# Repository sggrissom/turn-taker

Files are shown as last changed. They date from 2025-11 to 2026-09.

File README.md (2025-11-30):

# Turn Taker - RP2040 + SSD1315 OLED Project

A Raspberry Pi Pico project with SSD1315/SSD1306 I2C OLED display support.

## Prerequisites

1. **Pico SDK** - Install the Raspberry Pi Pico SDK:
   ```bash
   git clone https://github.com/raspberrypi/pico-sdk.git
   cd pico-sdk
   git submodule update --init
   export PICO_SDK_PATH=$(pwd)
   ```

2. **ARM Toolchain**:
   ```bash
   # Arch Linux
   sudo pacman -S arm-none-eabi-gcc arm-none-eabi-newlib

   # Ubuntu/Debian
   sudo apt install gcc-arm-none-eabi libnewlib-arm-none-eabi
   ```

3. **CMake** (version 3.13+):
   ```bash
   # Arch Linux
   sudo pacman -S cmake

   # Ubuntu/Debian
   sudo apt install cmake
   ```

## Wiring

Connect the SSD1315 OLED display to the Pico:

| Pico Pin | GPIO | Display Pin | Description  |
|---|---|---|---|
| 6 | GP4  | SDA | I2C Data |
| 7 | GP5  | SCL | I2C Clock |
| 36 | 3V3  | VCC | Power (3.3V) |
| 38 | GND  | GND | Ground |

```
         ┌─────────────────┐
         │  Raspberry Pi   │
         │      Pico       │
         │                 │
    SDA ─┤ GP4 (pin 6)     │
    SCL ─┤ GP5 (pin 7)     │
    VCC ─┤ 3V3 (pin 36)    │
    GND ─┤ GND (pin 38)    │
         └─────────────────┘
```

## Building

1. Set the SDK path (if not already set):
   ```bash
   export PICO_SDK_PATH=/path/to/pico-sdk
   ```

2. Create build directory and compile:
   ```bash
   mkdir build && cd build
   cmake ..
   make
   ```

3. The build produces `turn_taker.uf2` in the build directory.

## Flashing

1. Hold the **BOOTSEL** button on the Pico while connecting USB
2. The Pico will appear as a USB mass storage device (RPI-RP2)
3. Copy `turn_taker.uf2` to the device:
   ```bash
   cp build/turn_taker.uf2 /run/media/$USER/RPI-RP2/
   ```
4. The Pico will automatically reboot and run the program

## Configuration

Edit `include/config.h` to change:
- I2C pins (default: GP4/GP5)
- Display dimensions (default: 128x64)
- I2C address (default: 0x3C)

## Display Driver API

```c
// Initialize display
ssd1306_init(&display, I2C_PORT, addr, width, height);

// Clear buffer
ssd1306_clear(&display);

// Drawing functions
ssd1306_draw_pixel(&display, x, y, color);
ssd1306_draw_line(&display, x0, y0, x1, y1, color);
ssd1306_draw_rect(&display, x, y, w, h, color);
ssd1306_fill_rect(&display, x, y, w, h, color);
ssd1306_draw_char(&display, x, y, 'A', color);
ssd1306_draw_string(&display, x, y, "Hello", color);

// Send buffer to display
ssd1306_display(&display);

// Other controls
ssd1306_set_contrast(&display, 0xFF);
ssd1306_invert(&display, true);
```

## USB Serial Debug

The project is configured to output to USB serial. Connect via:
```bash
# Find the device
ls /dev/ttyACM*

# Connect (e.g., using minicom)
minicom -D /dev/ttyACM0 -b 115200
```

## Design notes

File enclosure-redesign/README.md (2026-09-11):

# Turn Taker — parametric enclosure (revision 1)

A code-driven replacement for the simple open-topped cup in
`../turn-taker/turn-taker/turn-taker/turn-taker.FCStd`. Nothing in the original
KiCad / FreeCAD / STEP files was modified — they are only read.

```
enclosure-redesign/
    enclosure.py        the whole model, parameters at the top
    README.md
    output/
        base.step  base.stl
        lid.step   lid.stl
        lid_print.stl           lid flipped + dropped to z=0, ready to slice
        button_plunger.step/.stl  optional, print 2 off
        build-report.txt        full validation log from the last run
        preview_*.png
```

## Building

```bash
cd enclosure-redesign
freecadcmd enclosure.py          # ~70 s, regenerates everything in output/
```

Requires FreeCAD ≥ 1.0 (1.1.1 here) with `numpy` + `matplotlib` for the
previews. No GUI, no CadQuery, no virtualenv — CadQuery was not installed and
FreeCAD headless already reads the KiCad STEP directly, so there was no reason
to add a dependency. Editing the model means editing the parameter block at the
top of `enclosure.py` and re-running; the script re-validates and re-exports
every time.

## Coordinate system

| | |
|---|---|
| X, Y | centred on the round PCB axis, Y up when looking at the component side |
| Z | 0 at the outside bottom of the base, +Z toward the lid |

Mapping from the KiCad STEP export:

```
x_local = x_step - 181.533565
y_local = y_step +  86.500000      (the STEP already has y = -kicad_y)
z_local = z_step + PCB_BOTTOM_Z    (the STEP has the PCB underside at z = 0)
```

## What the CAD told us

Everything below marked **derived** came out of `turn-taker.kicad_pcb`,
`turn-taker-PTH.drl` or `turn-taker.step`. Nothing here was guessed.

| Item | Value | Source |
|---|---|---|
| **PCB diameter** | **65.067 mm** (R 32.533565) | `Edge.Cuts` circle, centre (181.533565, 86.5) |
| PCB thickness | 1.51 mm in the STEP, **1.60 mm used** | STEP solid / KiCad nominal |
| Longest pin protrusion below the board | **1.91 mm** (SW1/SW2 legs) | STEP `ZMin = -1.905` |
| Plated through-holes | 62 | `turn-taker-PTH.drl` |
| Mounting holes usable for the case | **none** | the only NPTH are 4 holes inside the Pico footprint |
| Bottom-side components | **none** | `B_Paste.gbr` is empty — everything is THT |
| SW1 actuator | R 1.75 mm at (−19.884, +0.250), top 4.385 mm above the board | R1.75 cylinder in the STEP |
| SW2 actuator | R 1.75 mm at (−19.884, −14.250), same height | ditto |
| Tallest component | **J2, 8.54 mm** above the PCB top face | STEP bounding boxes |
| Pico USB micro-B | 7.50 mm wide at local X −0.259, 1.085–3.535 mm above the board, face 2.2 mm inside the board edge | STEP section at the Pico's USB end |
| S1 (power slide switch) | pads at local (18.466, +5.0 / +0.3 / −4.4); courtyard 7.3 × 13.2 mm | `kicad_pcb` pads + `F.CrtYd` |
| Bat_In1 | horizontal JST-PH, entirely inside R 29.7 | STEP |

Net check from the schematic: **SW1 → GPIO14** (back / undo),
**SW2 → GPIO15** (next person), **J1 → the OLED** (GND, +5V, GP4/SDA, GP5/SCL),
**J2 + S1 → battery switching**, **Bat_In1 → battery**.

Component heights above the PCB top face:

| | mm |
|---|---|
| J2 (power header) | 8.54 |
| J1 (display connector) | 6.00 |
| Bat_In1 | 4.85 |
| SW1 / SW2 | 4.30 |
| A1 Pico (incl. USB) | 3.70 |

## The enclosure

Overall **Ø70.067 × 26.80 mm**. Base 24.60 mm tall, lid 2.20 mm on top of it.

### Key dimensions

| Parameter | Value |
|---|---|
| PCB radial clearance (`PCB_RADIAL_CLEAR`) | 0.50 mm → cavity R 33.034 |
| Wall thickness (`WALL_T`) | 2.00 mm → outer R 35.034 |
| Floor thickness (`FLOOR_T`) | 2.00 mm |
| Lid thickness (`LID_T`) | 2.20 mm |
| PCB elevation above the floor (`PCB_ELEVATION`) | 5.00 mm → PCB underside at z = 7.00, top face at z = 8.60 |
| PCB support height | 5.00 mm (3.09 mm spare over the 1.91 mm pin protrusion) |
| Lid internal clearance (`LID_INTERIOR_CLEAR`) | 16.00 mm above the PCB top face → lid underside at z = 24.60, **7.46 mm of headroom over J2** |
| Lid fit clearance (`LID_FIT_CLEAR`) | 0.30 mm radial / 0.60 mm diametral |
| Lid skirt | Ø65.47 outer, 2.00 mm thick, 4.00 mm deep, 0.80 mm lead-in chamfer |

### PCB support

Two things hold the board, and neither touches a solder joint:

1. **A continuous annular ledge** at z = 7.00, inner radius 31.43 mm
   (`LEDGE_W = 1.6`), giving **1.10 mm of bearing** all the way round. The
   outermost through-hole in the whole board is at R 29.11, so the ledge is
   clear of every pin by construction. Because the cavity *widens* going up,
   the ledge is a step, not an overhang — it needs no print support.
2. **Nine Ø5 mm posts** from the floor to z = 7.00, listed in `SUPPORT_POSTS`.
   The script checks every post against all 62 plated holes; the worst case is
   **4.73 mm** centre-to-centre, against a 4.10 mm requirement (post radius +
   a 1.6 mm assumed solder-joint radius). One post sits deliberately at
   (−19.9, −7.0), between SW1 and SW2, so button presses don't flex the board.

The board drops in from above, sits level, and cannot rock. There is no
retention clip yet — that was explicitly deferred.

### Lid openings

| Opening | Size | Centre (local X, Y) |
|---|---|---|
| **SW1 button** | Ø6.00 mm | (−19.884, +0.250) |
| **SW2 button** | Ø6.00 mm | (−19.884, −14.250) |
| **Display window** | 24.0 × 15.0 mm, R1.2 corners | (−0.70, **−7.00**) |
| Display module recess (in the lid underside) | 28.3 × 28.8 × 1.40 mm deep | (−0.70, −3.40) |
| **S1 power switch slot** | 7.0 × 13.0 mm, R1.5 corners | (18.466, +0.300) |
| **USB micro-B** (in the base wall) | 13.0 × 8.0 mm | X −6.76…+6.24, Z 7.20…15.20 |
| Lid pry notch (base rim) | R6.0 × 1.6 mm deep scallop | at 270°, i.e. (0, −35.03) |

Button openings are 6.00 mm over a 3.50 mm actuator — **1.25 mm of annular
clearance**, so print tolerance and lid misalignment can't jam them.

The USB slot is sized for a plug overmould, not just the receptacle: the port
face sits 2.2 mm inside the board edge and there is another 2.0 mm of wall, so
the plug has to enter the case by about 5 mm before it engages.

### Edge access

- **Pico USB micro-B** — reaches the perimeter, so it gets a side slot. This is
  both the charging/serial port and the BOOTSEL flashing path, so it is not
  optional.
- **S1 power switch** — sits ~10 mm inside the board edge, so a side opening is
  geometrically impossible. It gets a slot in the lid instead (see assumptions).
- **Bat_In1 / J1 / J2** — entirely internal (max radius 29.7 mm); no openings,
  per the brief.

## Printing

0.4 mm nozzle, ordinary PLA/PETG settings. **Neither part needs supports.**

| Part | Orientation | Notes |
|---|---|---|
| `base.stl` | as exported, floor on the bed | Longest bridge is the 13 mm USB slot roof. The PCB ledge is a step that narrows going up, so it self-supports. |
| `lid_print.stl` | as exported (already flipped, outer face on the bed) | Gives the best finish on the visible face. `lid.stl` is the same part in assembly position if you'd rather orient it yourself. |
| `button_plunger.stl` | as exported, stem down — **print 2** | The flange overhang is picked up by a 45° cone. |

Minimum wall anywhere is 2.00 mm, except the 0.80 mm bezel that remains over
the display recess (4 layers at 0.2 mm).

## Assembly

1. Drop the two plungers into the lid's button holes **from underneath** (the
   8.5 mm flange won't pass through the 6 mm hole).
2. Seat the OLED module face-down into the lid recess and tape/glue it; route
   its 4 wires to J1.
3. Lower the PCB into the base — it lands on the ledge and the nine posts.
   Check the USB port lines up with the wall slot.
4. Press the lid on. The skirt locates it; 0.30 mm radial clearance should give
   a light friction fit. To open, push up through the pry notch in the rim.

## Assumptions (things the CAD could not tell us)

These are the only guesses in the model. Each is a parameter near the top of
`enclosure.py`.

1. **Display position and size.** There is *no display footprint on the PCB* —
   the SSD1315 is a separate module on flying leads to J1, so nothing in the
   CAD says where it physically sits. Dimensions assume the ubiquitous 0.96"
   4-pin I²C OLED: **27.3 × 27.8 mm module PCB, 21.74 × 10.86 mm active area**.
   The module is mounted **to the lid** (recess + window), which also keeps it
   clear of everything on the board. Position was chosen so the window centres
   on the midpoint between SW1 and SW2. Adjust `DISPLAY_MODULE_W/H`,
   `DISPLAY_CENTER`, `DISPLAY_WINDOW_W/H` and `DISPLAY_WINDOW_OFFSET`.
   *Measure your actual module before printing the lid.*
2. **S1 actuator.** Its footprint position is derived, but there is no 3D model
   for it, so its body and actuator height are unknown. The 7 × 13 mm lid slot
   covers the courtyard with clearance. With the lid 16 mm above the board this
   is a fingernail/stylus reach, not a comfortable thumb slide — a printed
   slider is a good rev-2 addition.
3. **Button reach.** The brief asked for plain holes so buttons could be pressed
   directly, but J2's 8.5 mm header sets the internal height, which leaves the
   actuators **13.82 mm below the lid's outer face** — far too deep for a
   fingertip through a 6 mm hole. The holes are still plain (a pen works), and
   the optional `button_plunger` bridges the gap properly. Set
   `BUTTON_PLUNGER_ENABLE = False` if you don't want them.
4. **Wiring volume.** `LID_INTERIOR_CLEAR = 16.00` is deliberately generous —
   8.54 mm of it is J2, the remaining 7.46 mm is for the display's flying
   leads and for a Dupont shell on J2 if you use one. Reduce it to ~12 mm if
   you solder wires directly and want a slimmer puck.
5. **Battery.** Bat_In1 implies a LiPo, but nothing in the CAD says where it
   lives. The model assumes it goes in the volume above the board. If you want
   it *under* the board instead, raise `PCB_ELEVATION` — there is currently
   only 5.00 mm there, 1.91 mm of which is pin protrusion.
6. **Solder joint size.** Posts are kept 1.6 mm (`POST_KEEPOUT`) away from any
   hole centre, on top of the post radius.
7. **PCB thickness.** The STEP solid is 1.51 mm; 1.60 mm is used so the pocket
   is never tight.

## Validation

`enclosure.py` runs 35 checks on every build and writes them to
`output/build-report.txt`. They cover: PCB fit and ledge bearing, pin
clearance, every support post against all 62 drilled holes, boolean
intersection of both enclosure parts against the real PCB assembly imported
from the STEP, lid headroom vs. the tallest component, button holes vs. the
actual actuator axes, plunger fit and travel, display window/recess layout and
its margins to the other lid features, skirt clearance, USB slot alignment
against the real port bounding box, minimum wall thickness, bridge length, and
a watertight/manifold/self-intersection check on each exported mesh.

Last run: **35/35 passed**, all three meshes watertight, manifold and free of
self-intersections.

## Previews

| File | |
|---|---|
| `preview_base.png` | base alone |
| `preview_lid_top.png` / `preview_lid_bottom.png` | lid outside / inside |
| `preview_top.png` | lid layout looking straight down |
| `preview_pcb_in_base.png` | PCB seated in the base |
| `preview_exploded.png` | exploded assembly |
| `preview_assembled.png` | assembled |
| `preview_section.png` | vertical section — ledge, posts, plunger, stack-up |

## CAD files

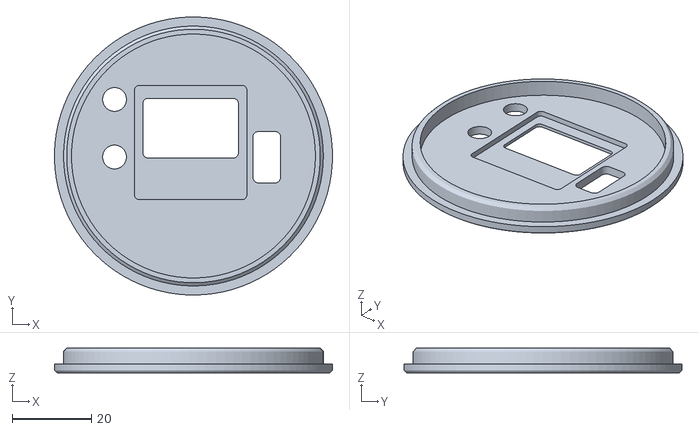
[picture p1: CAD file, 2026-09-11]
enclosure-redesign/output/lid_print.stl
70.0 x 70.1 x 6.20

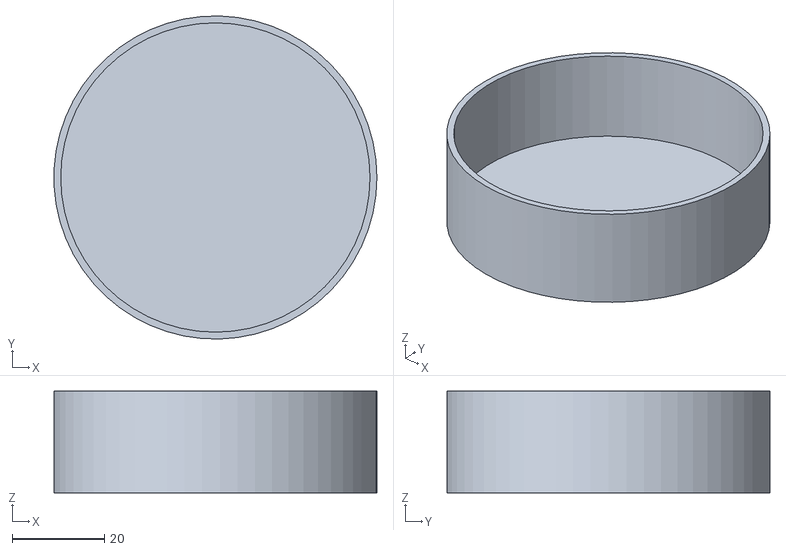
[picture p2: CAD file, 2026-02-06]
turn-taker/turn-taker/turn-taker/turn-taker-base.stl
69.9 x 70.0 x 22.0

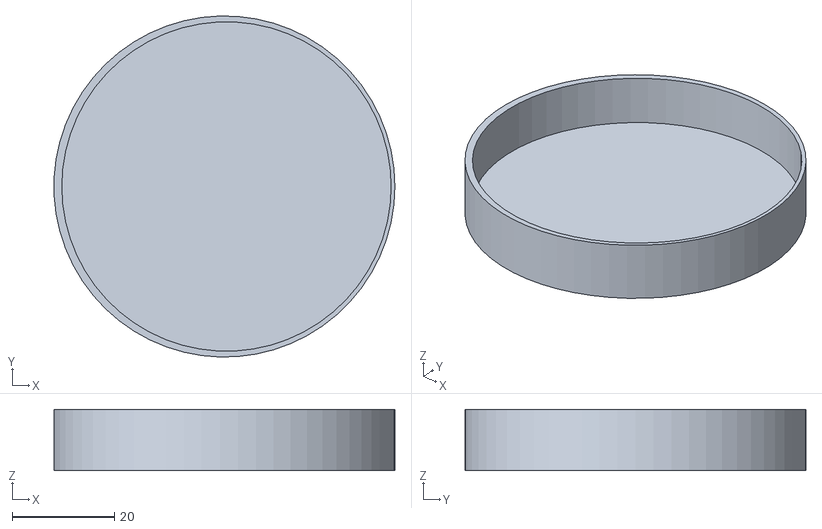
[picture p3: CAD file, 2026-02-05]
turn-taker/turn-taker/turn-taker/turn-taker-BodyPocket.stl
66.7 x 66.8 x 12.0

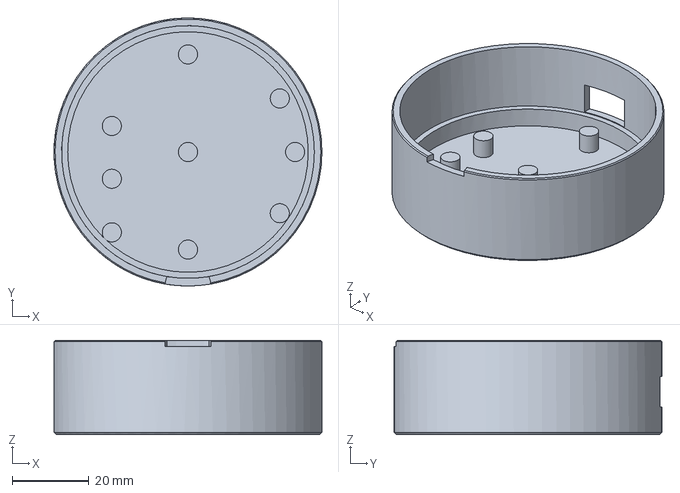
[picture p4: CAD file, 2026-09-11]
enclosure-redesign/output/base.step
70.1 x 70.1 x 24.6 mm

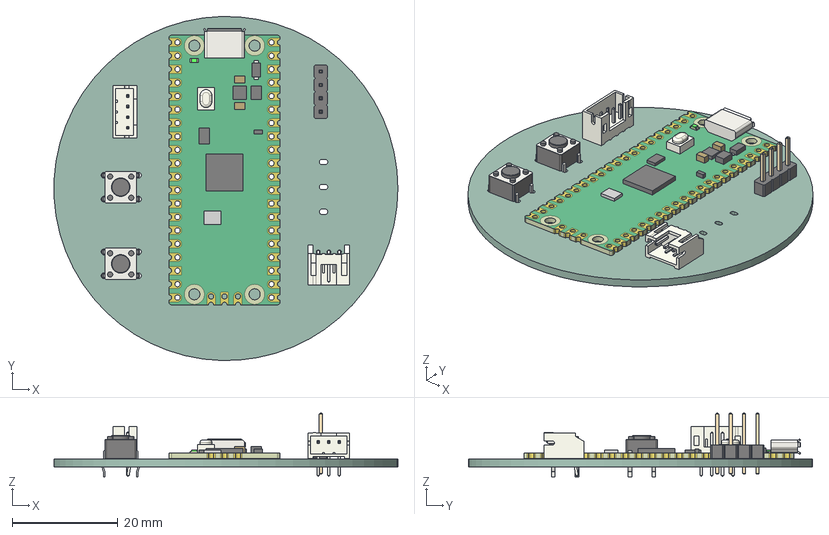
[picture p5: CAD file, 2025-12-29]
turn-taker/turn-taker/turn-taker/turn-taker.step
65.0 x 65.0 x 12.0 mm
RaspberryPi_Pico_Module_KiCad
PinHeader_1x04_P2.54mm_Vertical
SW_PUSH_6mm x 2
JST_PH_B4B-PH-K_1x04_P2.00mm_Vertical
JST_PH_S3B-PH-K_1x03_P2.00mm_Horizontal
turn-taker_PCB

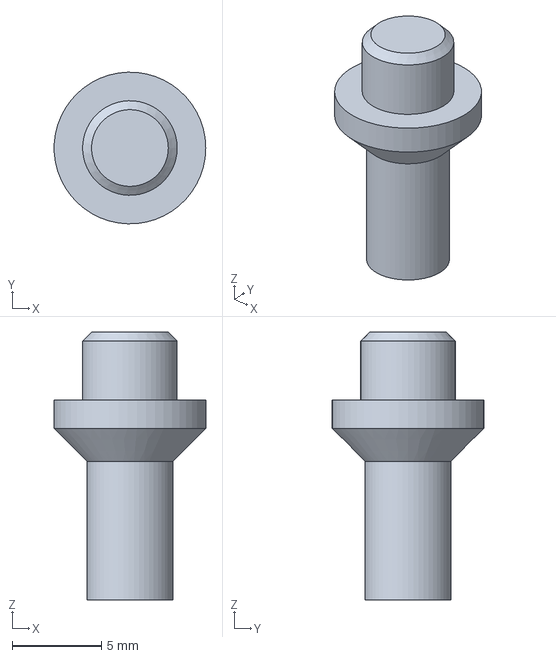
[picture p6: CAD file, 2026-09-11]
enclosure-redesign/output/button_plunger.step
8.49 x 8.50 x 15.0 mm

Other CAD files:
enclosure-redesign/output/lid.step
enclosure-redesign/output/base.stl
enclosure-redesign/output/button_plunger.stl
enclosure-redesign/output/lid.stl
turn-taker/turn-taker/turn-taker/turn-taker.FCStd

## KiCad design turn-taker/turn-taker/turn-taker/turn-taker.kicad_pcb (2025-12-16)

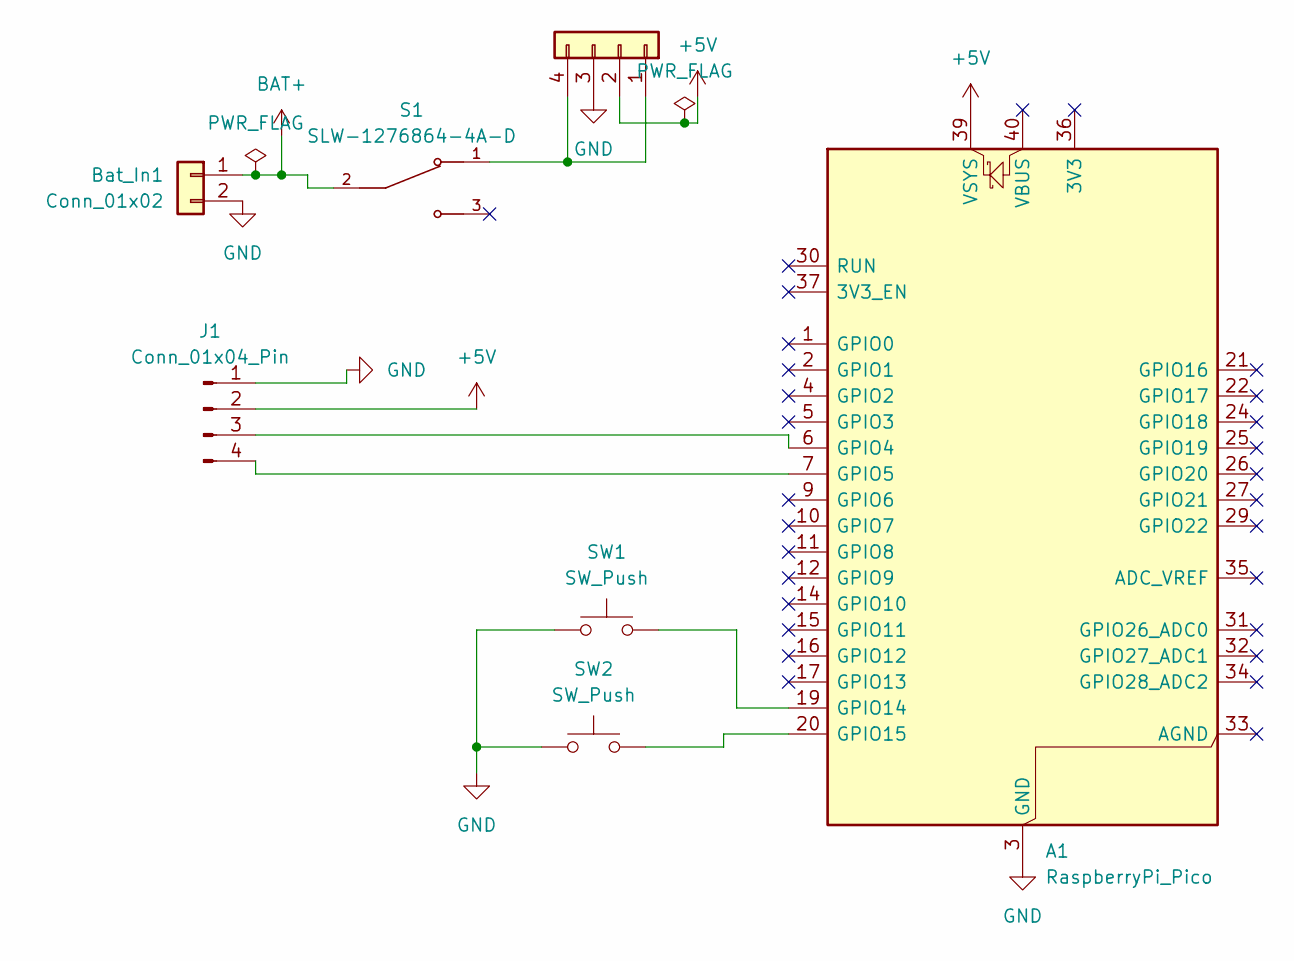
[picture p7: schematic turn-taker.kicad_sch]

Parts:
A1: RaspberryPi_Pico; RaspberryPi_Pico_Common_Unspecified
Bat_In1: Conn_01x02; JST_PH_S3B-PH-K_1x03_P2.00mm_Horizontal
J1: Conn_01x04_Pin; JST_PH_B4B-PH-K_1x04_P2.00mm_Vertical
J2: Conn_01x04; PinHeader_1x04_P2.54mm_Vertical
S1: SLW-1276864-4A-D; SW_SLW-1276864-4A-D; PARTREV 1.01
SW1, SW2: SW_Push; SW_PUSH_6mm

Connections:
+5V: A1.39 (VSYS), J1.2, J2.2
BAT+: Bat_In1.1, S1.2
GND: A1.3 (GND), A1.8 (GND), A1.13 (GND), A1.18 (GND), A1.23 (GND), A1.28 (GND), A1.38 (GND), Bat_In1.2, J1.1, J2.3, SW1.1, SW2.1
unnamed: A1.6 (GPIO4), J1.3
unnamed: A1.7 (GPIO5), J1.4
unnamed: A1.19 (GPIO14), SW1.2
unnamed: A1.20 (GPIO15), SW2.2
unnamed: J2.1, J2.4, S1.1

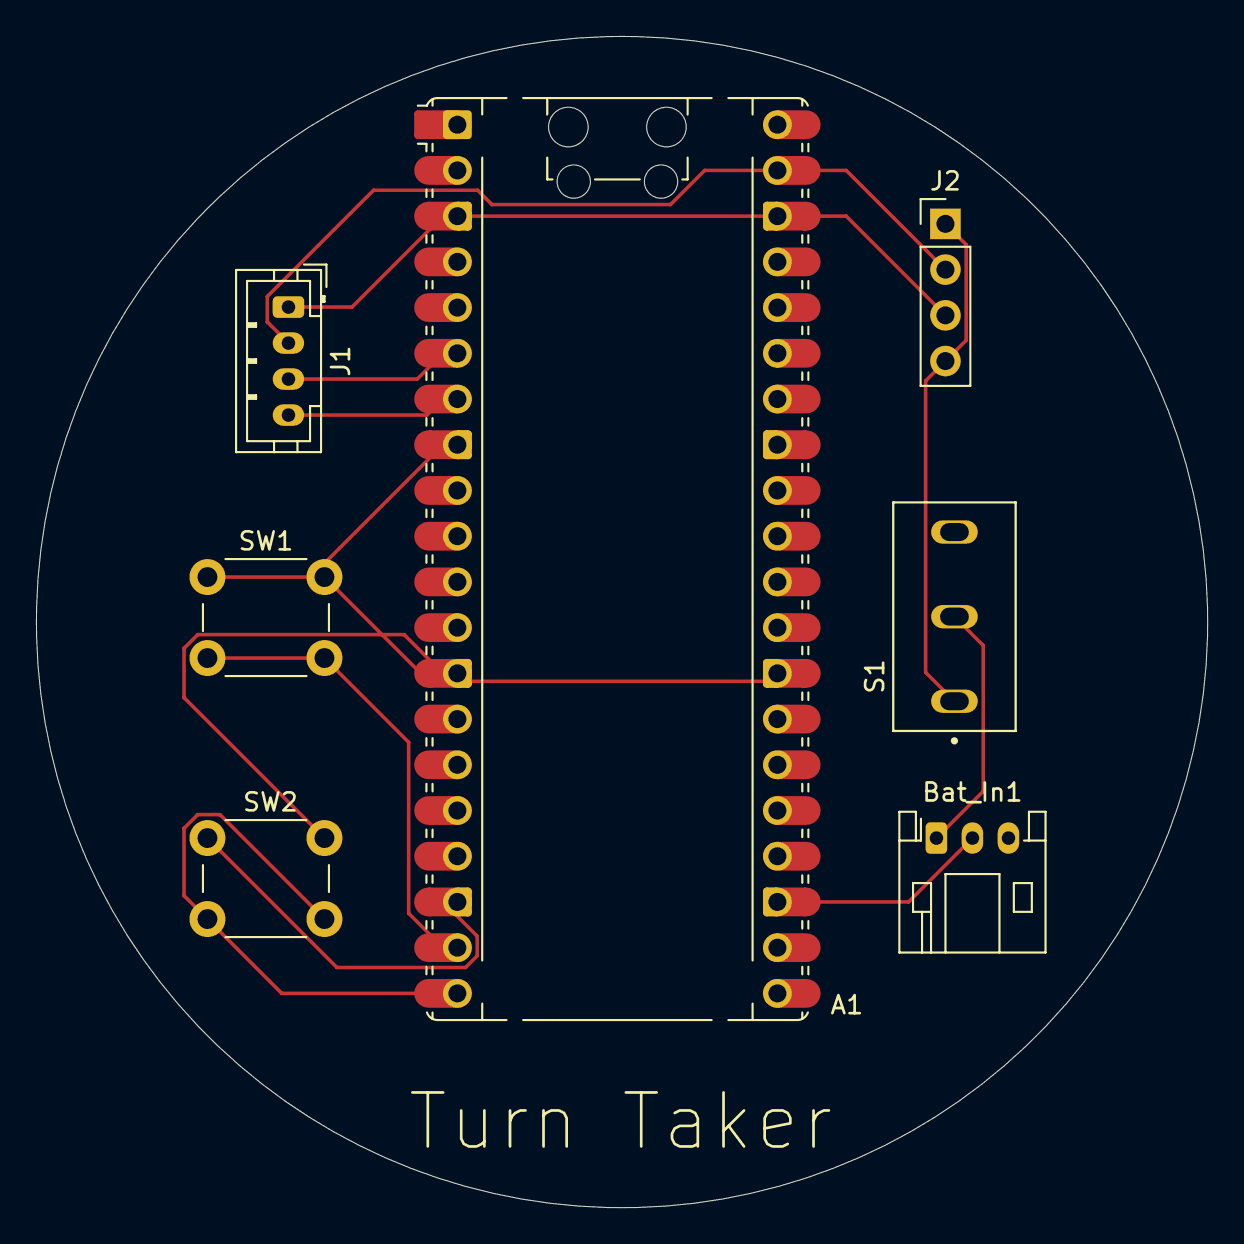
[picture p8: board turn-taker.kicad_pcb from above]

Board: 2 copper layers, 65.1 x 65.1 mm, 7 parts (0 on the bottom side), 8 nets.

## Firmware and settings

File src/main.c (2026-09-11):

#include <stdio.h>
#include <string.h>
#include "pico/stdlib.h"
#include "hardware/flash.h"
#include "hardware/sync.h"
#include "config.h"

// Flash storage for persistent state
// Use last sector of 2MB flash (offset from start of flash)
#define FLASH_TARGET_OFFSET (2 * 1024 * 1024 - FLASH_SECTOR_SIZE)
#define SAVE_MAGIC 0x5455524E  // "TURN" in hex

// `current` sits at the same offset it had in the two-name build, so a device
// updated in place comes back up on whoever it was already showing.
typedef struct {
    uint32_t magic;
    uint8_t current;
    uint8_t padding[3];
} save_data_t;

static void save_state(uint8_t current) {
    // Buffer must be FLASH_PAGE_SIZE (256 bytes) for flash_range_program
    uint8_t buffer[FLASH_PAGE_SIZE] = {0};
    save_data_t *data = (save_data_t*)buffer;
    data->magic = SAVE_MAGIC;
    data->current = current;

    // Must disable interrupts during flash operations
    uint32_t ints = save_and_disable_interrupts();

    // Erase the sector (required before writing)
    flash_range_erase(FLASH_TARGET_OFFSET, FLASH_SECTOR_SIZE);

    // Write the data (must be multiple of FLASH_PAGE_SIZE)
    flash_range_program(FLASH_TARGET_OFFSET, buffer, FLASH_PAGE_SIZE);

    restore_interrupts(ints);
}

static bool load_state(uint8_t *current) {
    // Flash is memory-mapped, so we can read it directly
    const save_data_t *data = (const save_data_t *)(XIP_BASE + FLASH_TARGET_OFFSET);

    if (data->magic == SAVE_MAGIC) {
        *current = data->current;
        return true;
    }
    return false;
}

#if ENABLE_DISPLAY
#include "hardware/i2c.h"
#include "ssd1306.c"

static ssd1306_t display;

// Rotation order. Appending keeps the saved index meaning what it used to.
static const char *names[] = {"Maia", "Adalie", "Aria"};
static const uint8_t num_names = 3;

// UI constants
#define BORDER_MARGIN 2
#define LINE_MARGIN 8
#define NAME_SCALE 3
#define DOT_SIZE 5
#define DOT_SPACING 8

static uint8_t get_name_len(const char *name) {
    uint8_t len = 0;
    for (const char *p = name; *p; p++) len++;
    return len;
}

// Draw one person's screen at a horizontal offset (for animation): their name
// large and centred, who follows them, and a dot per person with theirs filled.
static void draw_content(uint8_t name_index, int16_t x_offset) {
    const char *name = names[name_index];
    int16_t text_width = get_name_len(name) * 6 * NAME_SCALE;
    int16_t text_height = 7 * NAME_SCALE;

    // Layout calculations
    int16_t line_y1 = 10;
    int16_t name_y = line_y1 + 6;
    int16_t line_y2 = name_y + text_height + 4;
    int16_t footer_y = line_y2 + 7;

    // Name, centred, with the offset applied
    int16_t name_x = (DISPLAY_WIDTH - text_width) / 2 + x_offset;
    ssd1306_draw_string_scaled(&display, name_x, name_y, name, NAME_SCALE, false);

    // Horizontal rules (black)
    ssd1306_draw_line(&display, LINE_MARGIN + x_offset, line_y1,
                      DISPLAY_WIDTH - LINE_MARGIN + x_offset, line_y1, false);
    ssd1306_draw_line(&display, LINE_MARGIN + x_offset, line_y2,
                      DISPLAY_WIDTH - LINE_MARGIN + x_offset, line_y2, false);

    // Footer left: who is up after this turn
    ssd1306_draw_string(&display, LINE_MARGIN + x_offset, footer_y, "next: ", false);
    ssd1306_draw_string(&display, LINE_MARGIN + 6 * 6 + x_offset, footer_y,
                        names[(name_index + 1) % num_names], false);

    // Footer right: position in the rotation, right-aligned to the rules
    int16_t dots_width = (num_names - 1) * DOT_SPACING + DOT_SIZE;
    int16_t dots_x = DISPLAY_WIDTH - LINE_MARGIN - dots_width + x_offset;
    int16_t dots_y = footer_y + 1;
    for (uint8_t i = 0; i < num_names; i++) {
        int16_t x = dots_x + i * DOT_SPACING;
        if (i == name_index) {
            ssd1306_fill_rect(&display, x, dots_y, DOT_SIZE, DOT_SIZE, false);
        } else {
            ssd1306_draw_rect(&display, x, dots_y, DOT_SIZE, DOT_SIZE, false);
        }
    }
}

// The white page and its border sit still while the content slides over them.
static void draw_frame(void) {
    ssd1306_fill_rect(&display, 0, 0, DISPLAY_WIDTH, DISPLAY_HEIGHT, true);
    ssd1306_draw_rect(&display, BORDER_MARGIN, BORDER_MARGIN,
                      DISPLAY_WIDTH - 2 * BORDER_MARGIN,
                      DISPLAY_HEIGHT - 2 * BORDER_MARGIN, false);
}

static void draw_screen(uint8_t name_index) {
    draw_frame();
    draw_content(name_index, 0);
    ssd1306_display(&display);
}

// Slide from one person to the next. `forward` sends the old name out to the
// left (NEXT); going BACK runs the same motion mirrored, so an undo visibly
// rewinds rather than looking like another advance.
static void animate_transition(uint8_t old_index, uint8_t new_index, bool forward) {
    const int16_t steps = 12;
    const int16_t direction = forward ? 1 : -1;

    for (int16_t i = 1; i <= steps; i++) {
        // Scale by i/steps rather than a rounded-down step size, so the last
        // frame lands the incoming name exactly centred instead of snapping.
        int16_t offset = i * DISPLAY_WIDTH / steps * direction;

        draw_frame();
        draw_content(old_index, -offset);
        draw_content(new_index, direction * DISPLAY_WIDTH - offset);

        ssd1306_display(&display);
        sleep_ms(25);
    }

    // Final frame - ensure perfectly centered
    draw_screen(new_index);
}

#if ENABLE_DEEP_SLEEP
#include "hardware/clocks.h"
#include "hardware/pll.h"
#include "hardware/xosc.h"
#include "pico/runtime_init.h"

// Level-sensitive wake, not edge: the GPIO edge detector is clocked from
// clk_sys, which is stopped while dormant.
#define DORMANT_WAKE_EVENTS GPIO_IRQ_LEVEL_LOW

// Put every clock on the crystal so nothing is left running from a PLL when the
// PLLs stop. clk_sys in particular must not be PLL-derived or the core will not
// come back when the crystal restarts.
static void clocks_run_from_xosc(void) {
    clock_configure(clk_ref, CLOCKS_CLK_REF_CTRL_SRC_VALUE_XOSC_CLKSRC, 0,
                    XOSC_HZ, XOSC_HZ);
    clock_configure(clk_sys, CLOCKS_CLK_SYS_CTRL_SRC_VALUE_CLK_REF, 0,
                    XOSC_HZ, XOSC_HZ);
    clock_configure(clk_peri, 0, CLOCKS_CLK_PERI_CTRL_AUXSRC_VALUE_CLK_SYS,
                    XOSC_HZ, XOSC_HZ);
    clock_stop(clk_usb);
    clock_stop(clk_adc);
    clock_stop(clk_rtc);
    pll_deinit(pll_sys);
    pll_deinit(pll_usb);
}

// Halt the RP2040 until a button pulls its pin low. ROSC is deliberately left
// running: clocks_init() briefly parks clk_ref on it while rebuilding the PLLs.
static void enter_dormant(void) {
    clocks_run_from_xosc();

    gpio_set_dormant_irq_enabled(NEXT_BUTTON_PIN, DORMANT_WAKE_EVENTS, true);
    gpio_set_dormant_irq_enabled(BACK_BUTTON_PIN, DORMANT_WAKE_EVENTS, true);

    xosc_dormant();  // Returns once a button is pressed

    gpio_set_dormant_irq_enabled(NEXT_BUTTON_PIN, DORMANT_WAKE_EVENTS, false);
    gpio_set_dormant_irq_enabled(BACK_BUTTON_PIN, DORMANT_WAKE_EVENTS, false);

    // Restore the PLLs and the 125 MHz system clock, then rebuild I2C, whose
    // baud rate divisors were computed against the old clk_peri.
    clocks_init();
    i2c_init(I2C_PORT, I2C_BAUDRATE);
}
#endif

static void wait_for_buttons_released(void) {
    while (!gpio_get(NEXT_BUTTON_PIN) || !gpio_get(BACK_BUTTON_PIN)) {
        sleep_ms(20);
    }
    sleep_ms(20);  // Debounce the release
}

// Blank the panel and idle until a button is pressed. Returns with the display
// lit again and the caller responsible for redrawing.
static void enter_sleep(void) {
    ssd1306_sleep(&display);

#if ENABLE_DEEP_SLEEP
    enter_dormant();
    // The module never lost power, but its controller comes back with the
    // charge pump down and the clocks it was configured against changed, so
    // bring it up through a full init rather than a bare display-on.
    ssd1306_init(&display, I2C_PORT, DISPLAY_I2C_ADDR, DISPLAY_WIDTH, DISPLAY_HEIGHT);
#else
    while (gpio_get(NEXT_BUTTON_PIN) && gpio_get(BACK_BUTTON_PIN)) {
        sleep_ms(20);
    }
    ssd1306_wake(&display);
#endif
}
#endif

int main() {
    stdio_init_all();

    // LED setup - quick blink to show code is running
    gpio_init(LED_PIN);
    gpio_set_dir(LED_PIN, GPIO_OUT);
    gpio_put(LED_PIN, 1);
    sleep_ms(100);
    gpio_put(LED_PIN, 0);

#if ENABLE_DISPLAY
    // Initialize I2C
    i2c_init(I2C_PORT, I2C_BAUDRATE);
    gpio_set_function(I2C_SDA_PIN, GPIO_FUNC_I2C);
    gpio_set_function(I2C_SCL_PIN, GPIO_FUNC_I2C);
    gpio_pull_up(I2C_SDA_PIN);
    gpio_pull_up(I2C_SCL_PIN);

    // Initialize buttons with internal pull-up
    gpio_init(NEXT_BUTTON_PIN);
    gpio_set_dir(NEXT_BUTTON_PIN, GPIO_IN);
    gpio_pull_up(NEXT_BUTTON_PIN);

    gpio_init(BACK_BUTTON_PIN);
    gpio_set_dir(BACK_BUTTON_PIN, GPIO_IN);
    gpio_pull_up(BACK_BUTTON_PIN);

    // Small delay to let the display power up
    sleep_ms(100);

    // Initialize the display
    ssd1306_init(&display, I2C_PORT, DISPLAY_I2C_ADDR, DISPLAY_WIDTH, DISPLAY_HEIGHT);

    // Load saved state or use defaults
    uint8_t current = 0;
    if (!load_state(&current)) {
        current = 0;
    }
    // Validate loaded values
    if (current >= num_names) current = 0;

    draw_screen(current);

    bool next_was_pressed = false;
    bool back_was_pressed = false;
    absolute_time_t last_activity = get_absolute_time();

    while (true) {
        bool next_pressed = !gpio_get(NEXT_BUTTON_PIN);
        bool back_pressed = !gpio_get(BACK_BUTTON_PIN);

        if (next_pressed || back_pressed) {
            last_activity = get_absolute_time();
        }

        // Advance the rotation on button release
        if (next_was_pressed && !next_pressed) {
            uint8_t old = current;
            current = (current + 1) % num_names;
            animate_transition(old, current, true);
            save_state(current);
        }

        // Step back on button release, to undo a mis-press
        if (back_was_pressed && !back_pressed) {
            uint8_t old = current;
            current = (current + num_names - 1) % num_names;
            animate_transition(old, current, false);
            save_state(current);
        }

        next_was_pressed = next_pressed;
        back_was_pressed = back_pressed;

        if (absolute_time_diff_us(last_activity, get_absolute_time()) >
            (int64_t)IDLE_TIMEOUT_MS * 1000) {
            enter_sleep();
            draw_screen(current);
            // The press that woke us is not a turn - swallow it by waiting for
            // the release and clearing the edge state the handlers act on.
            wait_for_buttons_released();
            next_was_pressed = false;
            back_was_pressed = false;
            last_activity = get_absolute_time();
        }

        sleep_ms(20);  // Debounce delay
    }
#else
    // Hardware debug test - LED blink + button test
    // LED blinks slowly by default
    // Next button (GP15): fast blink while held
    // Back button (GP14): solid on while held
    // Both buttons: very fast strobe
    printf("Hardware debug test starting...\n");

    // Initialize buttons with internal pull-up
    gpio_init(NEXT_BUTTON_PIN);
    gpio_set_dir(NEXT_BUTTON_PIN, GPIO_IN);
    gpio_pull_up(NEXT_BUTTON_PIN);

    gpio_init(BACK_BUTTON_PIN);
    gpio_set_dir(BACK_BUTTON_PIN, GPIO_IN);
    gpio_pull_up(BACK_BUTTON_PIN);

    uint32_t counter = 0;
    while (true) {
        bool next_pressed = !gpio_get(NEXT_BUTTON_PIN);  // GP15
        bool back_pressed = !gpio_get(BACK_BUTTON_PIN);  // GP14

        if (next_pressed && back_pressed) {
            // Both: very fast strobe (50ms)
            gpio_put(LED_PIN, (counter / 50) % 2);
        } else if (next_pressed) {
            // Next only: fast blink (100ms)
            gpio_put(LED_PIN, (counter / 100) % 2);
        } else if (back_pressed) {
            // Back only: solid on
            gpio_put(LED_PIN, 1);
        } else {
            // No buttons: slow blink (500ms)
            gpio_put(LED_PIN, (counter / 500) % 2);
        }

        sleep_ms(1);
        counter++;
    }
#endif

    return 0;
}

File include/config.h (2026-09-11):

#ifndef CONFIG_H
#define CONFIG_H

// Feature flags
#define ENABLE_DISPLAY 1

// Power saving
// After IDLE_TIMEOUT_MS with no button activity the panel is switched off and,
// with ENABLE_DEEP_SLEEP, the RP2040 goes dormant until a button is pressed.
// The waking press only lights the screen back up; it does not use a turn.
// Deep sleep stops every clock including USB, so it cannot be combined with
// a USB-stdio build (see ENABLE_USB_STDIO in CMakeLists.txt).
#define ENABLE_DEEP_SLEEP 1
#define IDLE_TIMEOUT_MS 60000

// LED Configuration (GP25 is the onboard LED on Pico)
#define LED_PIN 25

// I2C Configuration
#define I2C_PORT i2c0
#define I2C_SDA_PIN 4
#define I2C_SCL_PIN 5
#define I2C_BAUDRATE 400000  // 400 kHz

// SSD1315/SSD1306 Display Configuration
// Note: Display VCC needs 5V (VBUS pin 40), not 3.3V
#define DISPLAY_WIDTH 128
#define DISPLAY_HEIGHT 64
#define DISPLAY_I2C_ADDR 0x3C

// Button Configuration
// NEXT advances the rotation, BACK steps it the other way to undo a mis-press.
#define NEXT_BUTTON_PIN 15  // Next person (GP15, pin 20)
#define BACK_BUTTON_PIN 14  // Previous person (GP14, pin 19)

#endif // CONFIG_H

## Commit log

2025-11-30 switch to a unity build for the display library
2025-12-02 add simple button for hardware testing
2025-12-06 add a "defer" button
2025-12-07 adding kicad files, just started the schematic
    [turn-taker.kicad_pcb, turn-taker.kicad_sch]
2025-12-08 schematic fixes
    [turn-taker.kicad_sch]
2025-12-14 finshed the schematic with footprints
    [turn-taker.kicad_sch]
2025-12-14 laid out the board
    [turn-taker.kicad_pcb]
2025-12-14 generated gerber and drill files, v1
    [turn-taker-B_Cu.gbr, turn-taker-B_Mask.gbr, turn-taker-B_Paste.gbr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]
2025-12-15 fixed the switch type in the schematic to match the part
    [turn-taker.kicad_sch]
2025-12-15 update pcb with correct switch footprint
    [turn-taker.kicad_pcb]
2025-12-16 update the jst connector for the screen in the schematic, footprint, and the pcb
    [turn-taker.kicad_pcb, turn-taker.kicad_sch]
2025-12-16 update the gerber and drill files
    [turn-taker-B_Cu.gbr, turn-taker-B_Mask.gbr, turn-taker-B_Paste.gbr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]
2025-12-27 add buttons testing to the deployment test
2025-12-29 generate step file for 3d model
    [turn-taker.step]
2025-12-29 cad project start, pcb model imported
    [turn-taker.FCStd]
2026-02-05 simple ring 3d model
    [turn-taker-BodyPocket.stl, turn-taker.FCStd]
2026-02-05 adding a floor to the model
    [turn-taker-BodyPocket.stl, turn-taker.FCStd]
2026-02-06 3d model with constraints
    [turn-taker-base.stl, turn-taker.FCStd]
2026-09-11 build the enclosure programattically instead of using CAD software
    [base.step, base.stl, button_plunger.step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]
